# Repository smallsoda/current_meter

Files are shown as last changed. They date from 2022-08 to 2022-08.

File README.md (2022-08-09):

# Current meter
USB current meter is designed to measure the current of low-power devices

### Measurements
The meter has three operational ampifiers (OA) to extend current measurement range. Currents from 2 uA to 2 A can be measured. All OAs connected to the only one shunt resistor (1 Ohm).
- Amplifier 0 gain (OA0, microchip DA3): 1
- Amplifier 1 gain (OA1, microchip DA2): 40
- Amplifier 2 gain (OA2, microchip DA1): 391

### Modes
The meter transfers current data via USB (virtual COM-port). Meter modes can be changed by push button.

Long press changes **data format** (indicator: **LED1**):
- **TEXT** data
    - Number of LED blinks: :bulb:
    - Units: uA
    - Message example: `19037\r\n`
- **RAW JSON** data
    - Number of LED blinks: :bulb::bulb:
    - Units: ADC units (0 ... 4095)
    - Message example: `{"OA0": 23, "OA1": 944, "OA2": 2504}\r\n`
- **RAW SLIP** data
    - Number of LED blinks: :bulb::bulb::bulb:
    - Units: ADC units (0 ... 4095)
    - Message example: `C0 00 17 03 B0 09 C8 C0`
    - `uint16_t, big-endian`

Short press changes data **transmission period** (indicator: **LED2**):
- **1 ms** period
    - Number of LED blinks: :bulb:
    - Instant value in any mode
- **10 ms** period
    - Number of LED blinks: :bulb::bulb:
    - Average value out of 10 in *TEXT* mode, instant value in other modes
- **100 ms** period
    - Number of LED blinks: :bulb::bulb::bulb:
    - Average value out of 100 in *TEXT* mode, instant value in other modes

Meter mode settings are stored in EEPROM and saved after disconnection from USB

#### Device diagram
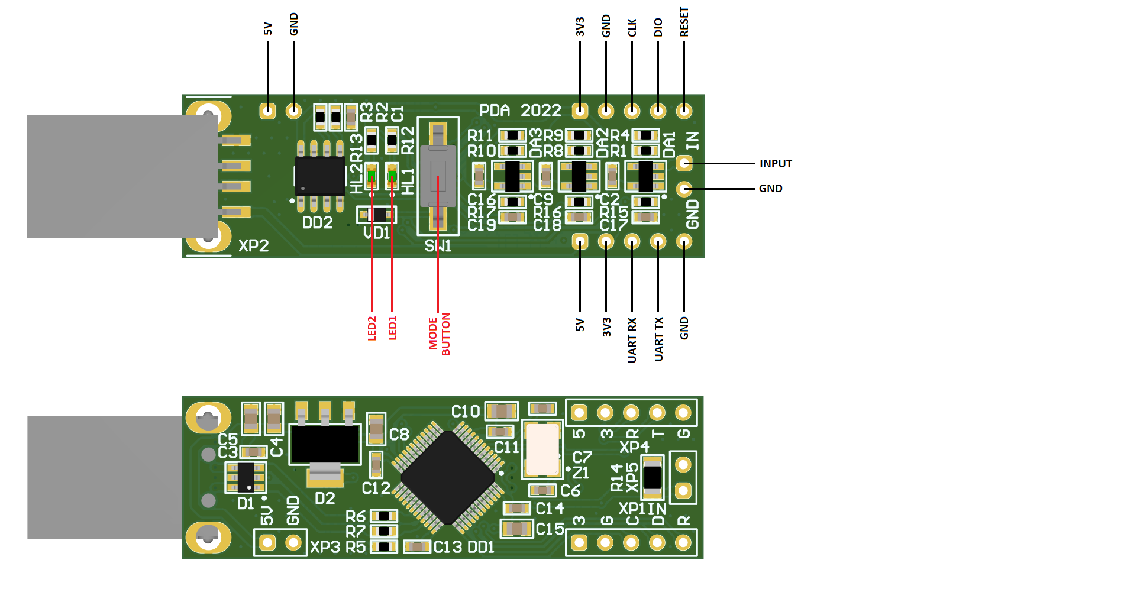
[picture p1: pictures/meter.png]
Device diagram


#### Connection diagram
The meter must be connected between the ground of the device whose current consumption is being measured and the ground of the power supply
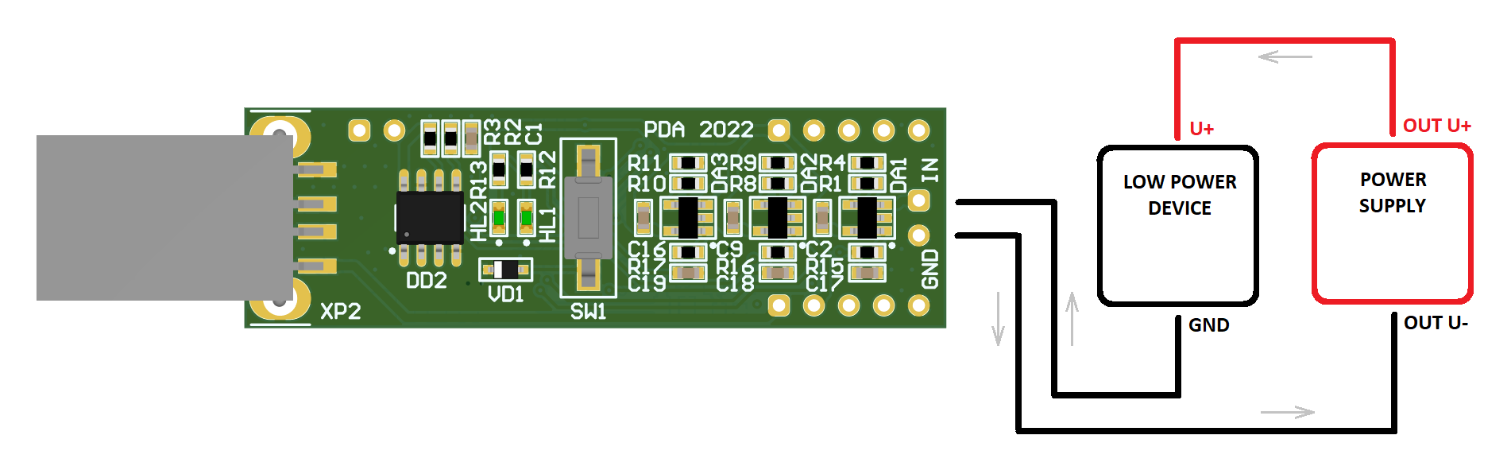
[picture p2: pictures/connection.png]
Connection diagram


#### Current chart
Any software can be used to render current chart. For example, Serial Plotter Tool in Arduino IDE
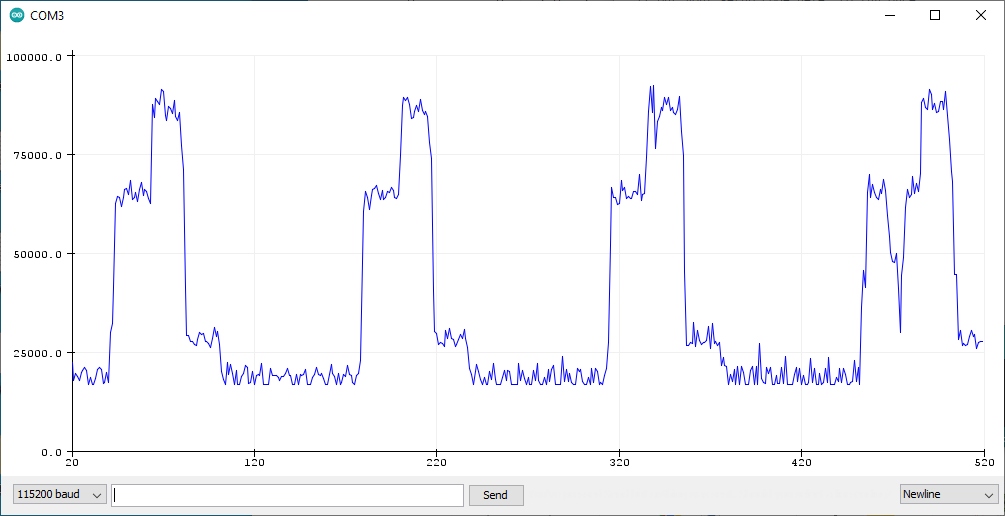
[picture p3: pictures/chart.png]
Current chart


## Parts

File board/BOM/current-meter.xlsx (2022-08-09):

Comment | Description | Designator | Footprint | Quantity
0.1u | 0603 CAP | C1, C2, C3, C9, C12, C13, C14, C16, C17, C18, C19 | 0603-CAP | 11
4.7u | 0805 CAP | C4, C5, C15 | 0805-CAP | 3
22p | 0603 CAP | C6, C7 | 0603-CAP | 2
1u | 0805 CAP | C8, C10 | 0805-CAP | 2
0.01u | 0603 CAP | C11 | 0603-CAP | 1
USBLC6-2SC6 | USBLC6-2SC6 | D1 | SOT-23-6L | 1
AZ1117EH-3.3 | AZ1117EH-3.3TRG1 | D2 | SOT-223 | 1
OPA333 | OPA333AIDBVR (TS321ILT) | DA1, DA2, DA3 | SOT-23-5 | 3
STM32F103C8T6 | STM32F103C8T6 | DD1 | LQFP48 | 1
M24C16-WMN6TP | M24C16-WMN6TP | DD2 | SOIC8 | 1
LED | 0603 LED | HL1, HL2 | 0603-LED | 2
39k | 0603 RES | R1, R8 | 0603-RES | 2
10k | 0603 RES | R2, R3 | 0603-RES | 2
100 | 0603 RES | R4 | 0603-RES | 1
1.5k | 0603 RES | R5 | 0603-RES | 1
22 | 0603 RES | R6, R7 | 0603-RES | 2
1k | 0603 RES | R9, R12, R13, R15, R16, R17 | 0603-RES | 6
0 | 0603 RES | R10 | 0603-RES | 1
NP | 0603 RES | R11 | 0603-RES | 1
1 | 1206 RES | R14 | 1206-RES | 1
KLS7-TS3608-5.0-180 | KLS7-TS3608-5.0-180 | SW1 | KLS7-TS3608-5.0-180 | 1
PESD5V0L1BA | PESD5V0L1BA,115 | VD1 | SOD-323 | 1
PLS-5 | PLS-5 | XP1 | PLS-5 | 1
USB type A | DS1098-B | XP2 | DS1098-B | 1
NP | PLS-2 | XP3, XP5 | PLS-2 | 2
PLS-5 | PLS-5 | XP4 | PLS-5 | 1
8MHz | 12.89048 (12.89007 -20+70) | Z1 | KX-9 | 1

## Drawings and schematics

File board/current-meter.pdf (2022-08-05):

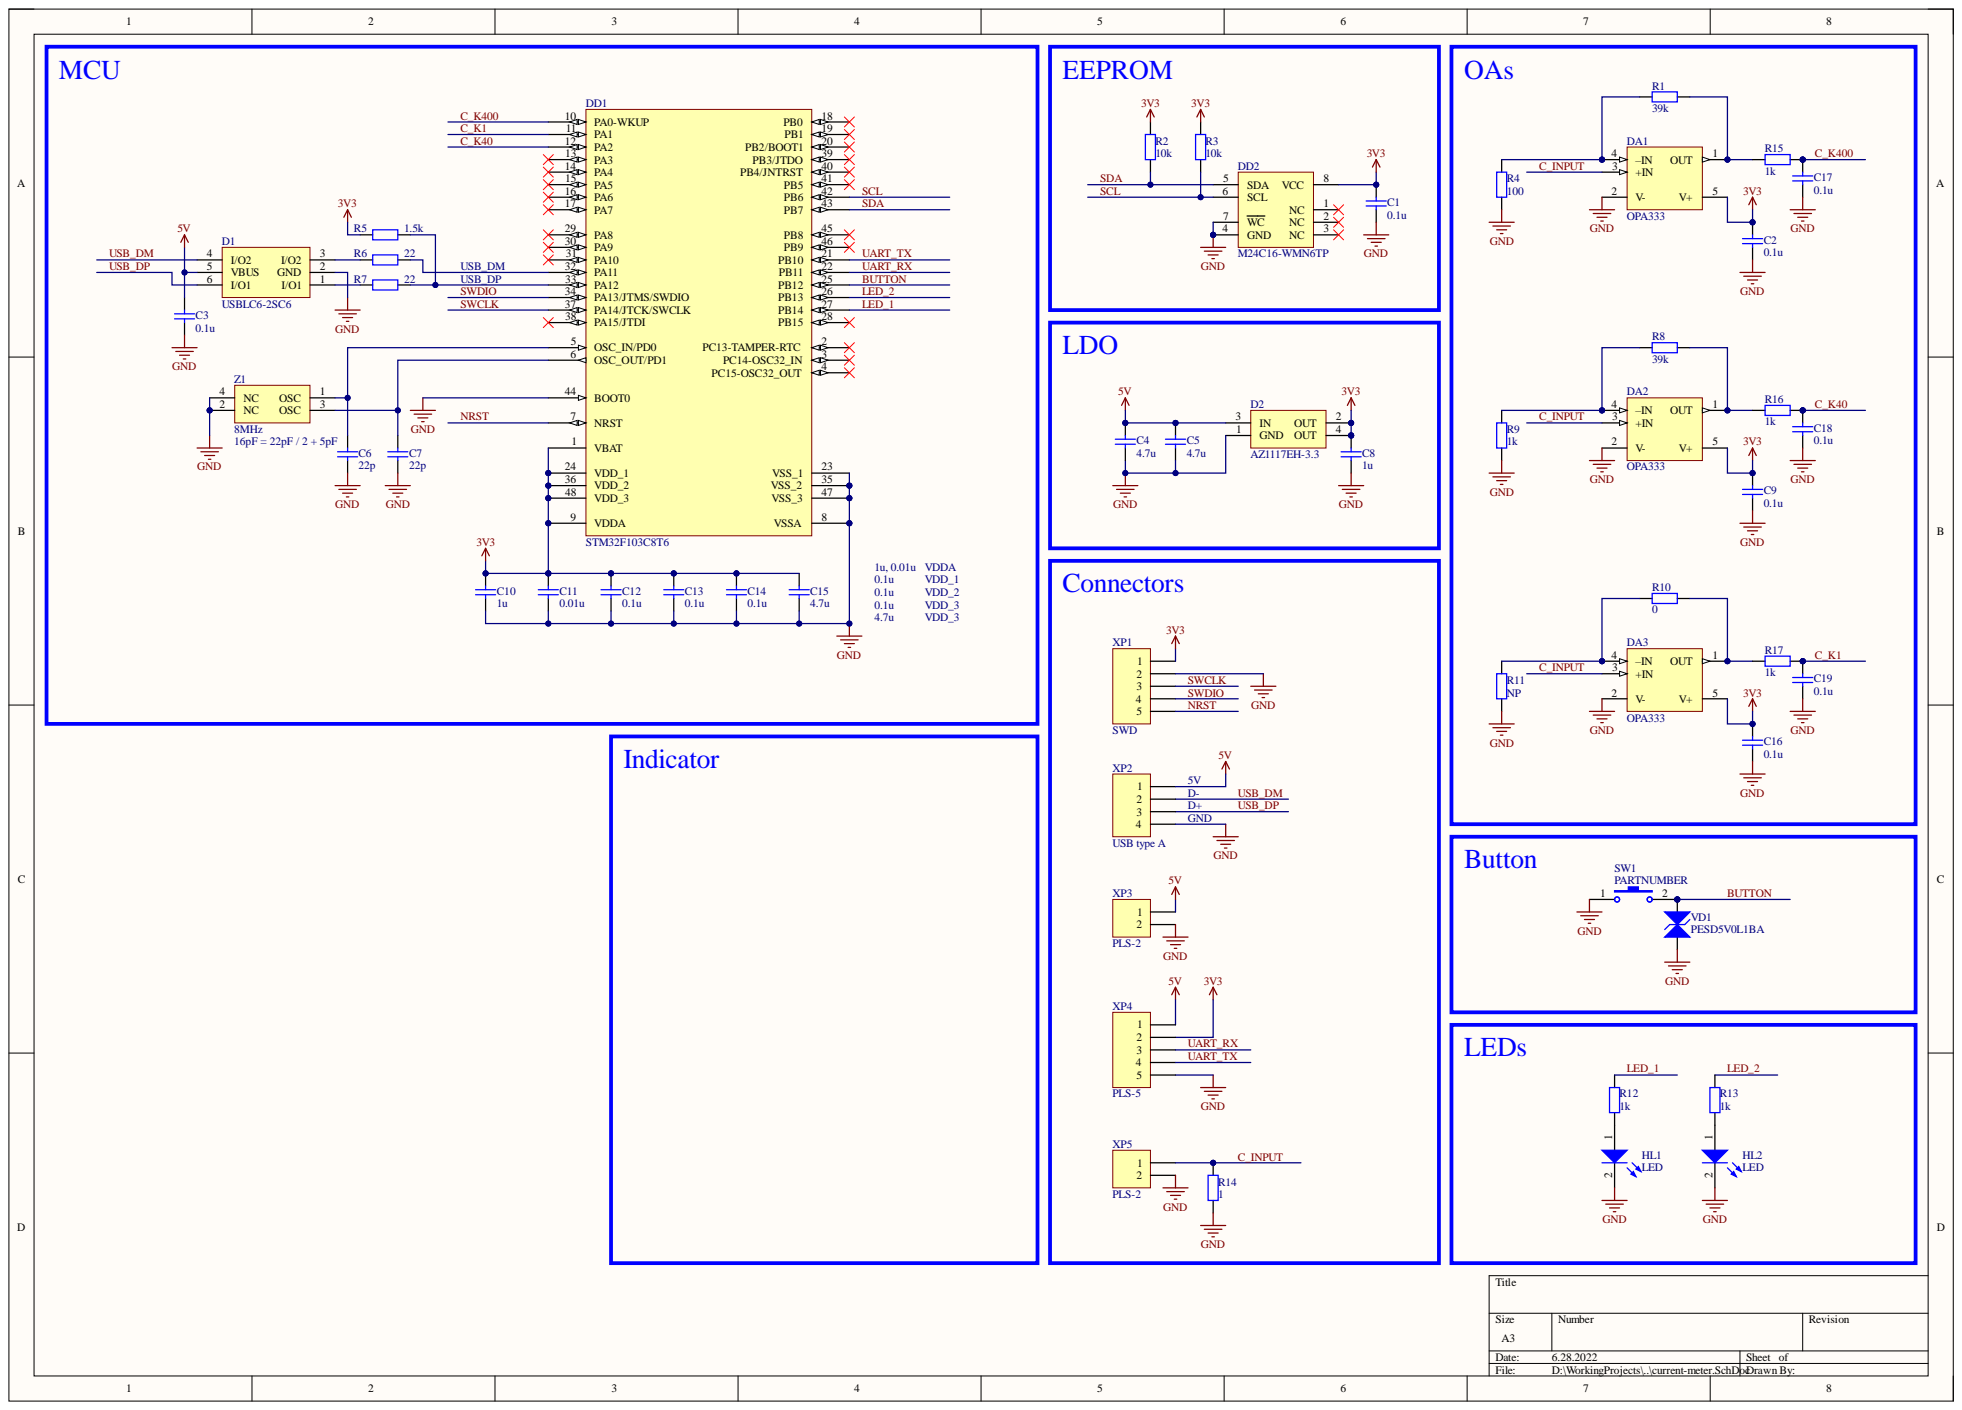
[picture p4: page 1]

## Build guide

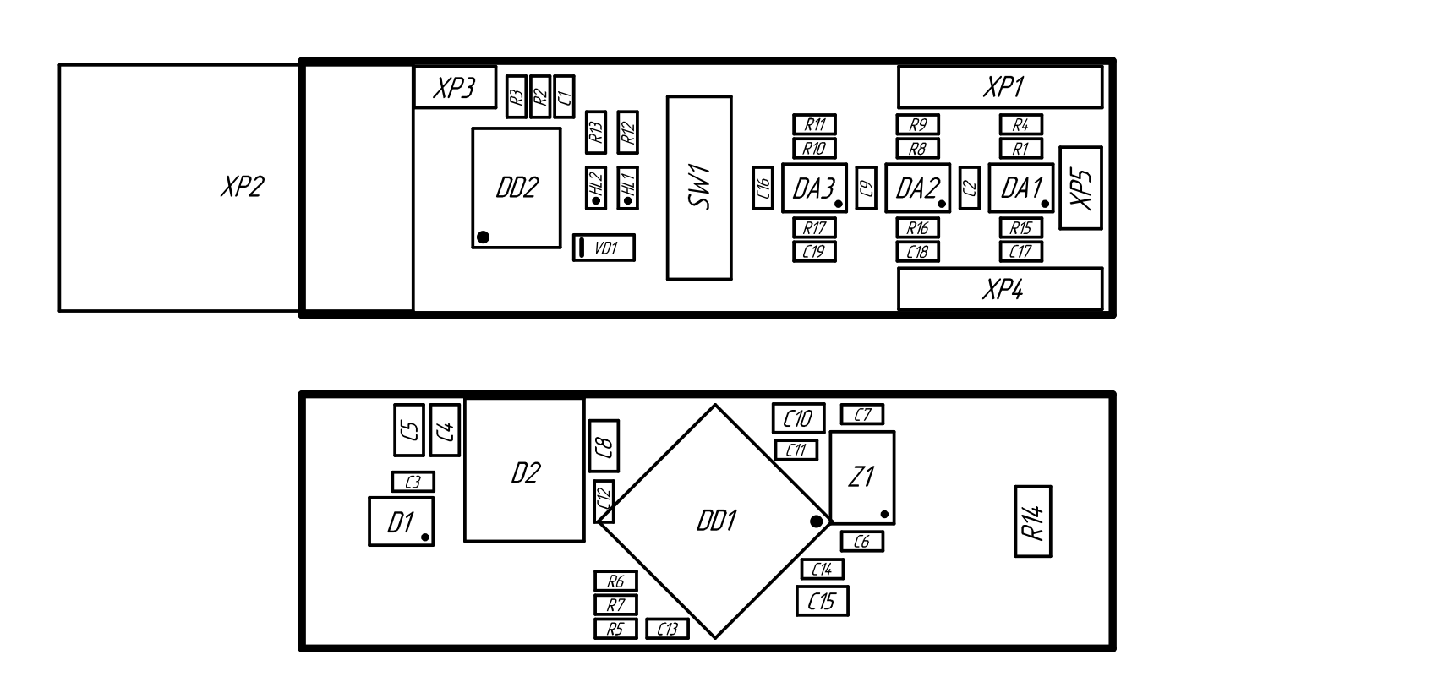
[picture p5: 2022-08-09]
board/Production/assembly.png

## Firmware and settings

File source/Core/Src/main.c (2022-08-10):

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
/* Includes ------------------------------------------------------------------*/
#include "main.h"
#include "usb_device.h"

/* USER CODE BEGIN Includes */

#include "usbd_cdc_if.h"

#include "slip.h"
#include "storage.h"
#include "status_led.h"

#define K_ADC_TO_UA 805.860806 // k = 1000000000 / 4095 * 3.3
#define OA_MAX_ADC_VALUE 2000
#define OA0_GAIN 1
#define OA1_GAIN 40
#define OA2_GAIN 391

#define DATA_BUFFER_SIZE 256
#define DATA_STRING_SIZE 1024

#define DATA_TX_MAX_RECORDS 50
#define DATA_TX_MAX_RETRIES 10

#define BUTTON_DELAY     200 // ms
#define BUTTON_DELAY_LP 1000 // ms

/* USER CODE END Includes */

 ADC_HandleTypeDef hadc1;
DMA_HandleTypeDef hdma_adc1;

I2C_HandleTypeDef hi2c1;

TIM_HandleTypeDef htim4;

/* USER CODE BEGIN PV */

// Storage
storage_t storage = {0};
uint8_t save_settings_flag = 0;

// ADC
uint16_t adc_data[3];

// Data buffer
uint16_t data_buffer_raw[DATA_BUFFER_SIZE][3];
uint32_t data_buffer[DATA_BUFFER_SIZE];
uint16_t data_buffer_set = 0;
uint16_t data_buffer_get = 0;
char data_string[DATA_STRING_SIZE];

/* USER CODE END PV */

void SystemClock_Config(void);
static void MX_GPIO_Init(void);
static void MX_I2C1_Init(void);
static void MX_DMA_Init(void);
static void MX_ADC1_Init(void);
static void MX_TIM4_Init(void);
/* USER CODE BEGIN 0 */

//
//
void HAL_TIM_PeriodElapsedCallback(TIM_HandleTypeDef *htim)
{
	// Button
	static uint16_t btn_counter = 0;
	static uint16_t btn_counter_press = 0;
	static uint8_t btn_state = 1;

	// General counter
	static uint16_t counter = 0;
	counter = (counter + 1) % 1000;

	// Period: 1ms
	// ADC
	//
	HAL_ADC_Start_DMA(&hadc1, (uint32_t *) adc_data, 3);

	// Period: 1ms
	// Button
	//
	if(btn_counter_press)
		btn_counter_press--;
	//
	if(btn_counter)
	{
		btn_counter--;
	}
	else
	{
		if((btn_state == 1) && (HAL_GPIO_ReadPin(GPIOB, GPIO_PIN_12) == GPIO_PIN_RESET))
		{
			btn_state = 0;
			btn_counter = BUTTON_DELAY;
			btn_counter_press = BUTTON_DELAY_LP;
		}
		else if((btn_state == 0) && (HAL_GPIO_ReadPin(GPIOB, GPIO_PIN_12) == GPIO_PIN_SET))
		{
			btn_state = 1;
			btn_counter = BUTTON_DELAY;

			// Short press
			if(btn_counter_press)
			{
				storage.settings.period = (storage.settings.period + 1) % 3; // 0 - 1ms, 1 - 10ms, 2 - 100ms
				status_led(0, storage.settings.period + 1); // 1, 2 or 3 blinks
				save_settings_flag = 1;
			}
			// Long press
			else
			{
				storage.settings.mode = (storage.settings.mode + 1) % 3; // 0 - TEXT, 1 - RAW JSON, 2 - RAW SLIP
				status_led(1, storage.settings.mode + 1); // 1, 2 or 3 blinks
				save_settings_flag = 1;
			}
		}
	}

	// Period: 125ms
	// LEDs
	//
	if((counter % 125) == 0)
		status_led_callback();
}

//
//
void HAL_ADC_ConvCpltCallback(ADC_HandleTypeDef* hadc)
{
	static uint16_t counter = 0;
	uint32_t value = 0;

	// Raw data
	data_buffer_raw[data_buffer_set][0] = adc_data[1];
	data_buffer_raw[data_buffer_set][1] = adc_data[2];
	data_buffer_raw[data_buffer_set][2] = adc_data[0];

	// OA2
	if(adc_data[0] < OA_MAX_ADC_VALUE)
		value = adc_data[0] * K_ADC_TO_UA / OA2_GAIN * storage.calib.oa2 / 1000;
	// OA1
	else if(adc_data[2] < OA_MAX_ADC_VALUE)
		value = adc_data[2] * K_ADC_TO_UA / OA1_GAIN * storage.calib.oa1 / 1000;
	// OA0
	else
		value = adc_data[1] * K_ADC_TO_UA / OA0_GAIN * storage.calib.oa0 / 1000;

	// Clear buffer
	if(counter == 0)
		data_buffer[data_buffer_set] = 0;

	// Period: 1ms
	if(storage.settings.period == 0)
	{
		data_buffer[data_buffer_set] = value;
		counter = 0; // ?
		data_buffer_set = (data_buffer_set + 1) % DATA_BUFFER_SIZE;
	}
	// Period: 10ms
	else if(storage.settings.period == 1)
	{
		data_buffer[data_buffer_set] += value;
		counter = (counter + 1) % 10;
		if(counter == 0)
		{
			data_buffer[data_buffer_set] /= 10;
			data_buffer_set = (data_buffer_set + 1) % DATA_BUFFER_SIZE;
		}
	}
	// Period: 100ms
	else if(storage.settings.period == 2)
	{
		data_buffer[data_buffer_set] += value;
		counter = (counter + 1) % 100;
		if(counter == 0)
		{
			data_buffer[data_buffer_set] /= 100;
			data_buffer_set = (data_buffer_set + 1) % DATA_BUFFER_SIZE;
		}
	}
}

/* USER CODE END 0 */

/**
  * @brief  The application entry point.
  * @retval int
  */
int main(void)
{
  /* MCU Configuration--------------------------------------------------------*/

  /* Reset of all peripherals, Initializes the Flash interface and the Systick. */
  HAL_Init();

  /* Configure the system clock */
  SystemClock_Config();

  /* Initialize all configured peripherals */
  MX_GPIO_Init();
  MX_I2C1_Init();
  MX_DMA_Init();
  MX_USB_DEVICE_Init();
  MX_ADC1_Init();
  MX_TIM4_Init();
  /* Infinite loop */
  /* USER CODE BEGIN WHILE */

  // EEPROM storage
  storage_get_params(&storage);
  if(storage.settings.empty_status != 0x5A)
  {
	  storage_set_default();
	  storage_get_params(&storage);
  }

  // LEDs
  status_led(0, storage.settings.period + 1);
  status_led(1, storage.settings.mode + 1);

  // ADC
  HAL_ADCEx_Calibration_Start(&hadc1);

  // TIM4
  HAL_TIM_Base_Start_IT(&htim4);

  while (1)
  {
    /* USER CODE END WHILE */

    /* USER CODE BEGIN 3 */

	    // Saving settings to storage
	    if(save_settings_flag)
	    {
	    	save_settings_flag = 0;
	    	storage_set_params_settings(&storage.settings);
	    }

		// Data transfer
	    if(data_buffer_get != data_buffer_set)
	    {
	    	// Create message
			uint16_t string_cnt = 0;
			uint16_t records = DATA_TX_MAX_RECORDS;

			// Mode: TEXT
			if(storage.settings.mode == 0)
			{
				while((data_buffer_get != data_buffer_set) && (records))
				{
					string_cnt += sprintf(&data_string[string_cnt], "%lu\r\n", data_buffer[data_buffer_get]);
					data_buffer_get = (data_buffer_get + 1) % DATA_BUFFER_SIZE;
					records--;
				}
			}

			// Mode: RAW JSON
			else if(storage.settings.mode == 1)
			{
				while((data_buffer_get != data_buffer_set) && (records))
				{
					string_cnt += sprintf(
							&data_string[string_cnt],
							"{\"OA0\": %d, \"OA1\": %d, \"OA2\": %d}\r\n",
							data_buffer_raw[data_buffer_get][0],
							data_buffer_raw[data_buffer_get][1],
							data_buffer_raw[data_buffer_get][2]);
					data_buffer_get = (data_buffer_get + 1) % DATA_BUFFER_SIZE;
					records--;
				}
			}

			// Mode: RAW SLIP
			else if(storage.settings.mode == 2)
			{
				while((data_buffer_get != data_buffer_set) && (records))
				{
					uint8_t buffer[6];
					for(uint8_t i = 0; i < 3; i++)
					{
						buffer[i * 2] = data_buffer_raw[data_buffer_get][i] >> 8;
						buffer[i * 2 + 1] = data_buffer_raw[data_buffer_get][i];
					}

					uint8_t *slip = NULL;
					string_cnt = slip_packet(&slip, buffer, 6);
					memcpy(data_string, slip, string_cnt);
					free(slip);

					data_buffer_get = (data_buffer_get + 1) % DATA_BUFFER_SIZE;
					records--;
		    	}
			}

			// Transfer message
			uint16_t retries = DATA_TX_MAX_RETRIES;
			while((CDC_Transmit_FS((uint8_t*) data_string, string_cnt) == USBD_BUSY) && (retries))
			{
				HAL_Delay(1);
				retries--;
			}
		}
  }
  /* USER CODE END 3 */
}

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


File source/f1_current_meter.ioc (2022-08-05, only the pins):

Mcu.UserName=STM32F103C8Tx
PA0-WKUP.Signal=ADCx_IN0
PA1.Signal=ADCx_IN1
PA11.Signal=USB_DM
PA12.Signal=USB_DP
PA13.Signal=SYS_JTMS-SWDIO
PA14.Signal=SYS_JTCK-SWCLK
PA2.Signal=ADCx_IN2
PB12.Signal=GPIO_Input
PB13.Signal=GPIO_Output
PB14.Signal=GPIO_Output
PB6.Signal=I2C1_SCL
PB7.Signal=I2C1_SDA
PD0-OSC_IN.Signal=RCC_OSC_IN
PD1-OSC_OUT.Signal=RCC_OSC_OUT

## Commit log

2022-08-09 Update BOM and hex
    [current-meter.xlsx]
2022-08-09 Add assembly
    [current-meter.PcbDoc]
2022-08-10 Add default calibration coefficients

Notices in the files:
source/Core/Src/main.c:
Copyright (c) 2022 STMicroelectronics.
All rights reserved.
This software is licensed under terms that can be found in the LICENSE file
